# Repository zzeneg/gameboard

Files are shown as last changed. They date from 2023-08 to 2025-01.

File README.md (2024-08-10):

# gameboard

Half-keyboard optimized for gaming.

## Features

- 31 regular MX or KS-33/27 switches
- 5-way switch
- 3 push buttons
- per-key LEDs
- 3D printed case

## Photos

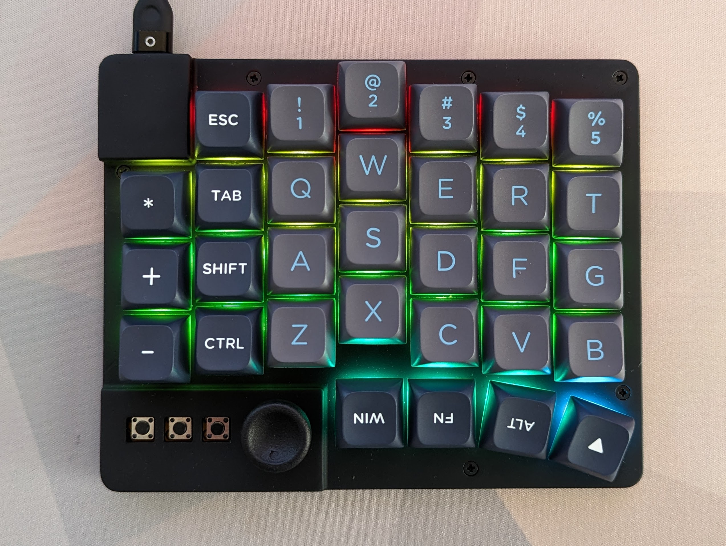
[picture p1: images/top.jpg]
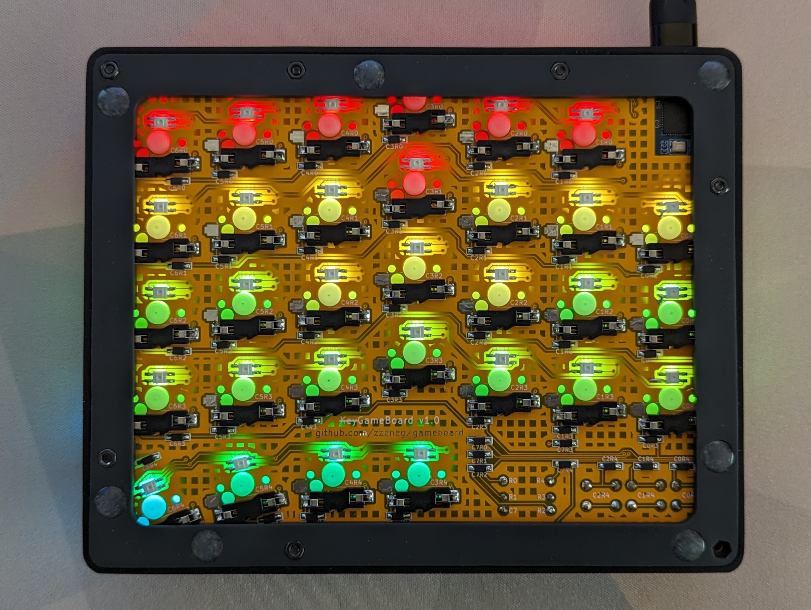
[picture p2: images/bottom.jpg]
 

## Layout

Optimized for regular WASD setup similar to a normal keyboard, to avoid (or at least minimize) remapping keys for games.

No layer-tap and mod-taps to avoid conflicts (many games require mod presses or holding alpha keys).

1 additional layer to access missing half of keyboard.

Anyway it's easy to change keys on the fly with VIAL.
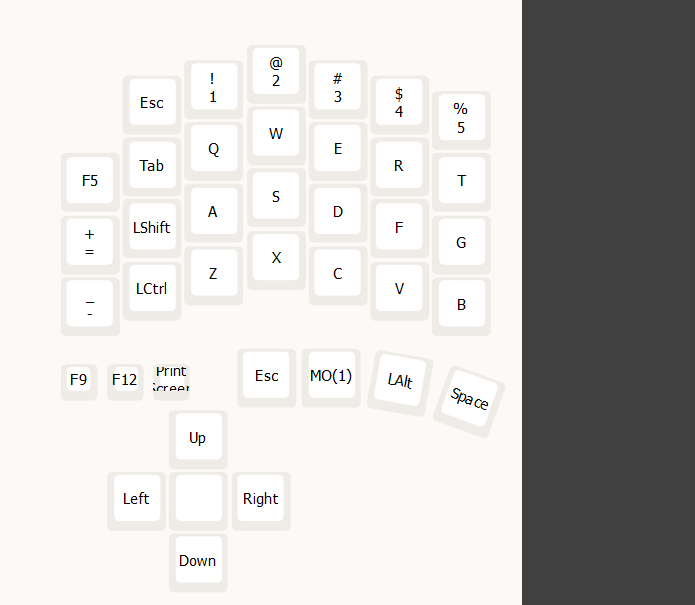
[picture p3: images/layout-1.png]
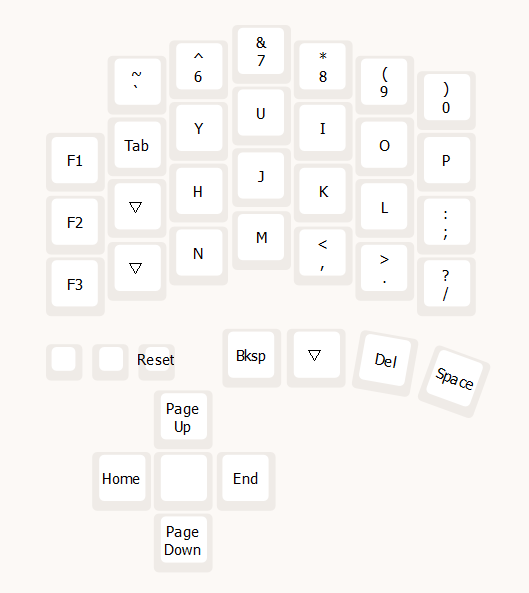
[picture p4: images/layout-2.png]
 

## Case

Tested on JLCPCB resin printing, it may be a bit tight for FDM.

- [KS-33 Top](./case/top.stl)
- [MX Top](./case/top-mx.stl)
- [Bottom](./case/bottom.stl)
- [5-way knob](./case/5way-short.stl) - lower profile knob, if you want higher profile check out ones from [@sadekbaroudi](https://github.com/sadekbaroudi/fingerpunch/tree/master/3d-models/5-way-tactile-switch-knobs)

## Gerber files

- [PCB](./pcb/production/pcb.zip)

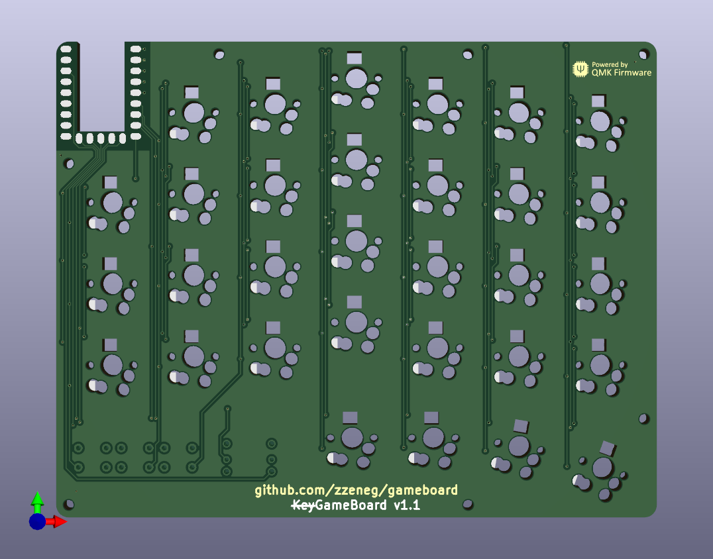
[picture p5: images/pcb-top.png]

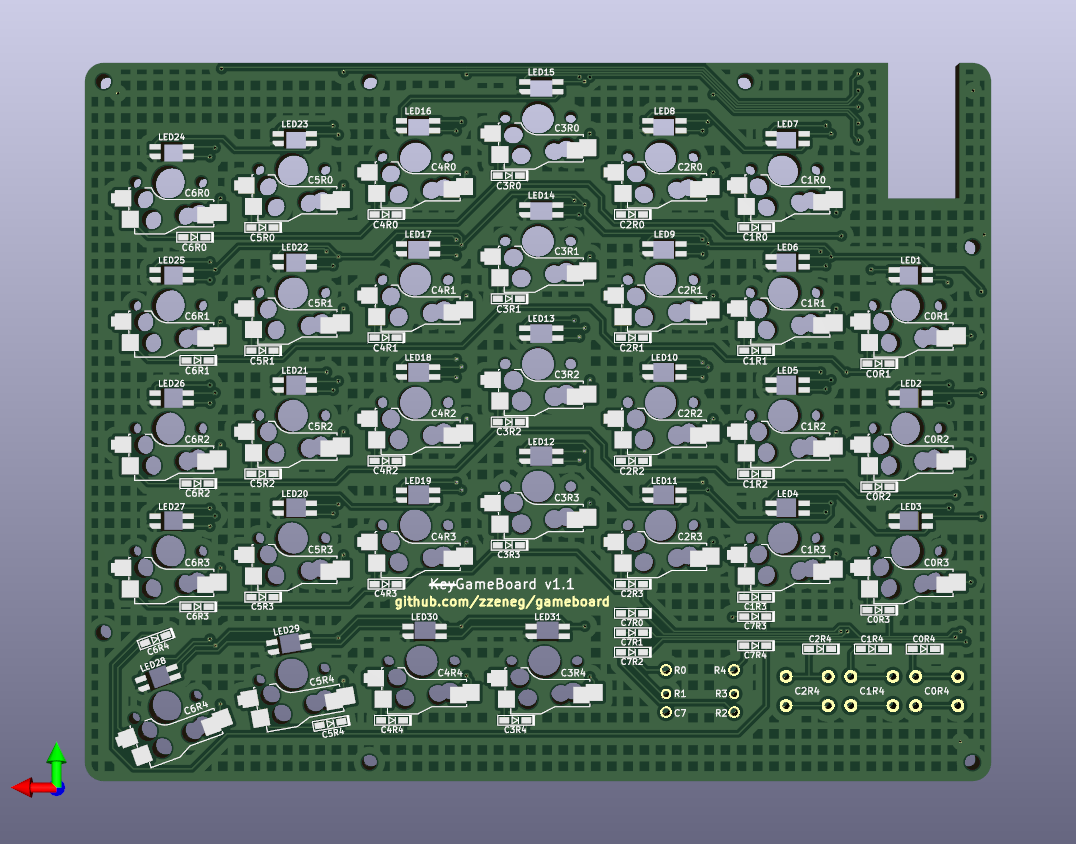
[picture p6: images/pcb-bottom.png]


## VIAL firmware

- [source code](https://github.com/zzeneg/vial-qmk/tree/feature/zzeneg/keyboards/gameboard)
- [pre-compiled V1](https://github.com/zzeneg/vial-qmk/releases/download/zzeneg/gameboard_v1_vial.uf2)
- [pre-compiled V2 (with display)](https://github.com/zzeneg/vial-qmk/releases/download/zzeneg/gameboard_v2_vial.uf2)

## Bill of materials

- [PCB](./pcb/production/pcb.zip)
- 3D printed parts (top, bottom, knob)
- Waveshare [RP2040 Zero](https://www.aliexpress.com/item/3256804090654134.html) MCU
- 39 [SMD SOD-123 1N4148](https://www.aliexpress.com/item/1005002882901030.html) diodes
- 1 [5way switch](https://www.aliexpress.com/item/4000681560472.html)
- 3 [push buttons](https://www.aliexpress.com/item/32912263133.html) - default height is 4.3mm but you can use 6-8mm if you want easier access to them
- 31 [RGB LEDs](https://www.aliexpress.com/item/1005003636607308.html)
- [M2 screws with flat head](https://www.aliexpress.com/item/4001248931159.html) - 8mm for MX or 8mm+6mm for KS
- [M2 nuts](https://www.aliexpress.com/item/1005001412230125.html)
- [7x1.5 legs](https://www.aliexpress.com/item/1005002995402961.html)

## Build guide

Please see my [stront guide](https://github.com/zzeneg/stront/blob/main/build-guide/choc/readme.md) for detailed instructions on soldering diodes/LEDs/sockets/MCU.

## MinY version (V2 - ProMicro-compatible, VIK support)

> [!CAUTION]
> This is special version designed for minimal vertical spacing (19x16mm). Regular keycaps will not fit, you must print your own. I prepared several [keycap sets](./case/minY/keycaps/) to choose.
>
> It uses Pro Micro format MCU so it could be wireless (not tested).
>
> I did not make/test case for MX switches - you can modify it in Fusion.

Updated BOM:

- [MCU](https://www.aliexpress.com/item/1005006130019224.html) - ProMicro pinout, bottom pins are needed for I2C and LED only
- [1.47" bare LCD](https://www.aliexpress.com/item/1005004833011998.html) with [VIK adapter](https://github.com/zzeneg/vik-display-adapter) (**PCB <= 1.2mm is recommended**)
- M2 [heatset inserts](https://www.aliexpress.com/item/1005004624377733.html) - 4mm length, 3.2mm diameter for resin case or 3.5mm for Nylon/PLA
- [push buttons](https://www.aliexpress.com/item/1005006143163980.html) - 10mm height for KS, 15mm for MX
- [push button caps](https://www.aliexpress.com/item/1005001584967258.html) - 3.1 inner diameter

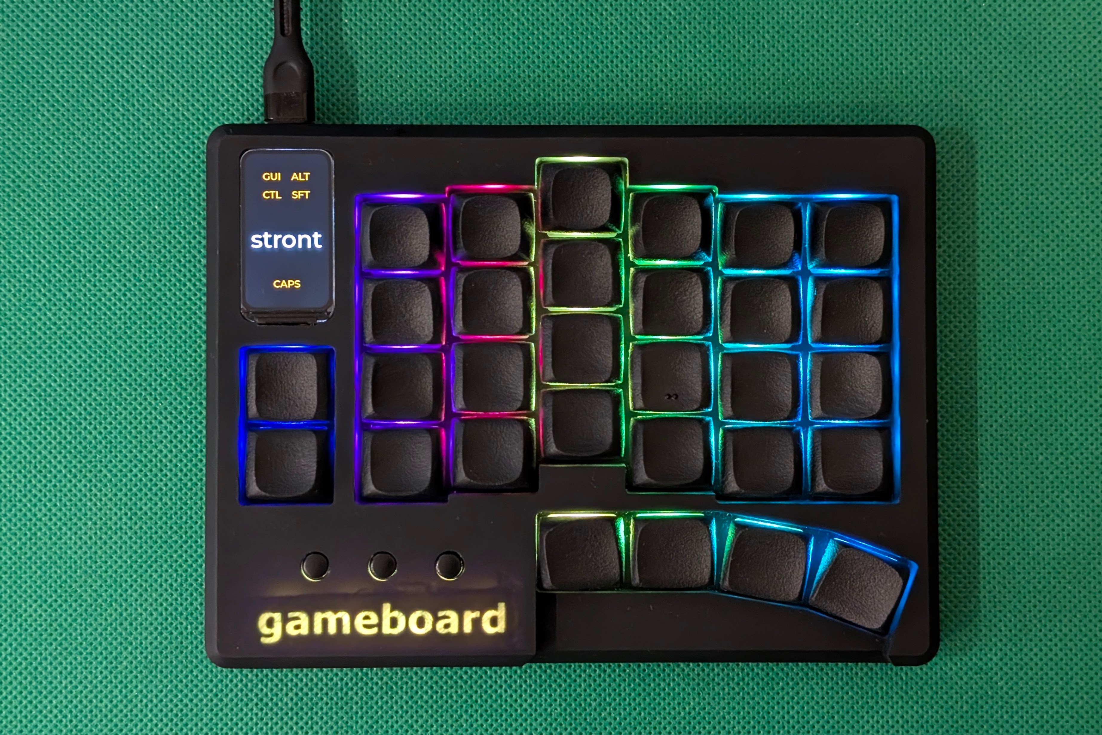
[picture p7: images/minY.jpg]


## Development

For proper KiCad setup install my [zzkeeb](https://github.com/zzeneg/zzkeeb/blob/main/README.md#installation) library

## Support

If you like my work and want to support my future designs, please consider [sponsorship](https://github.com/sponsors/zzeneg).

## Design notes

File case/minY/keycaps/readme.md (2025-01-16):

# Keycap sets for Gameboard MinY

Keycaps with minimal vertical spacing (19x16mm), sprued and adjusted to number of keys on Gameboard.

## DES minY minZ

Generated from [my fork](https://github.com/zzeneg/PseudoMakeMeKeyCapProfiles?tab=readme-ov-file#update-from-zzeneg).

Tested in MJF Nylon with KS-33, ChocV2, Tecsee Medium and regular MX switches.

## CMY

Alternative profile, see [CMY](https://github.com/sadekbaroudi/fingerpunch/tree/master/keycaps/CMY) from Sadek Baroudi.

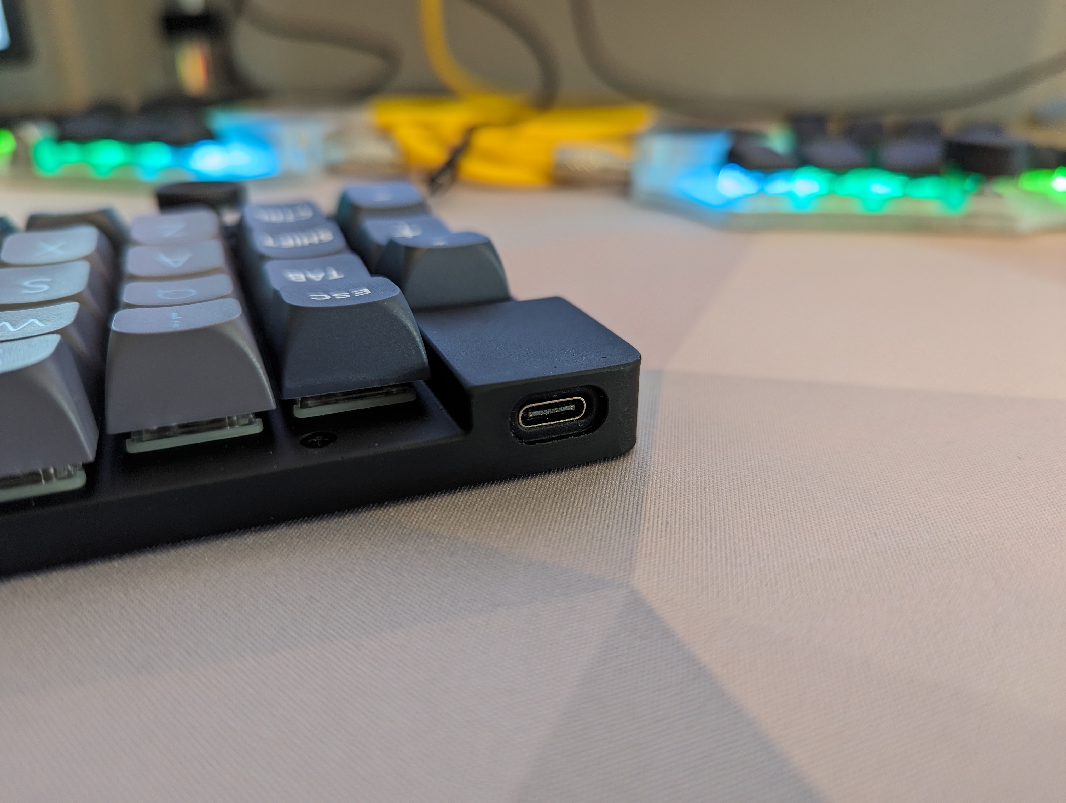
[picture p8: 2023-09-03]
images/usb.jpg

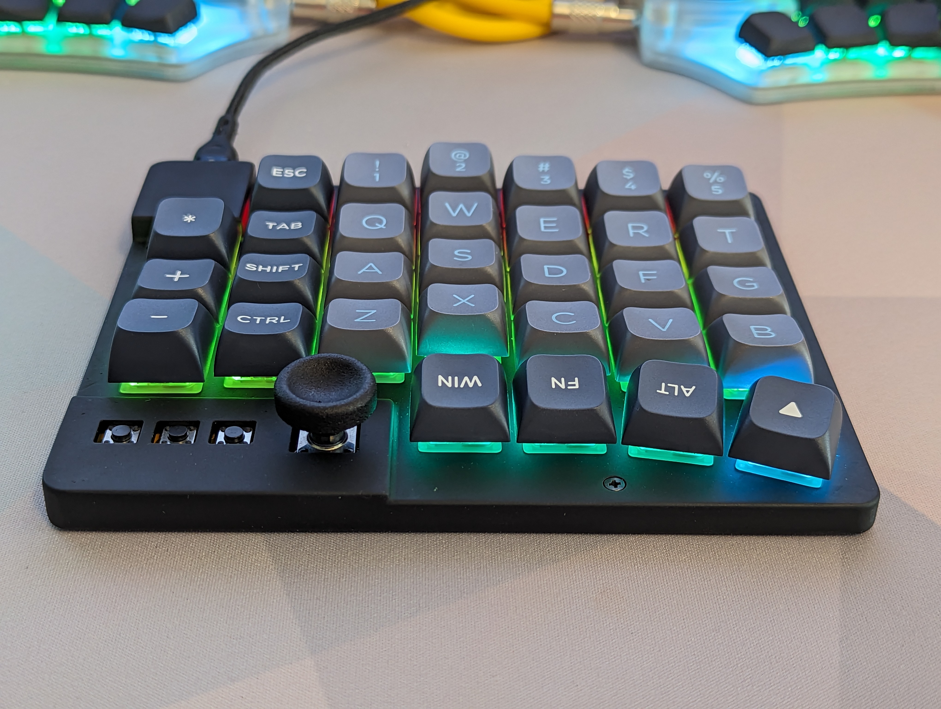
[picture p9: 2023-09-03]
images/side.jpg

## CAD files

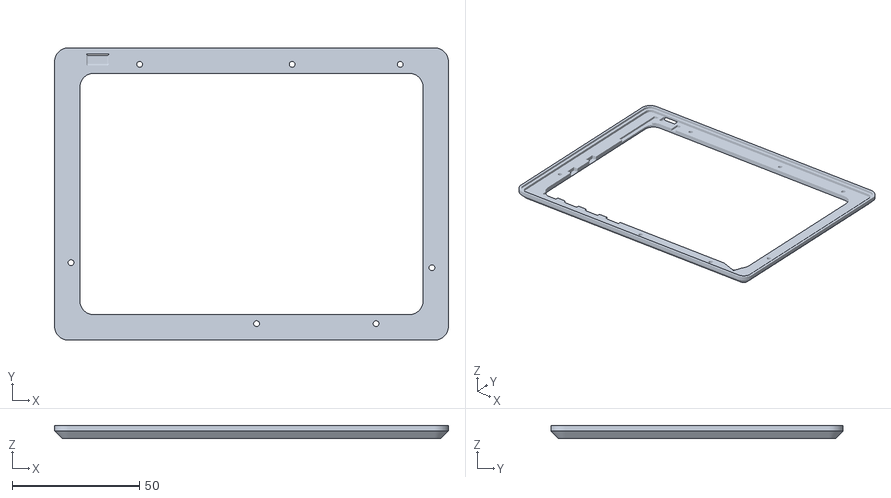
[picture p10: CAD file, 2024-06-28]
case/minY/miny-v2-ks-bottom-wireless.stl
155.0 x 115.0 x 5.10

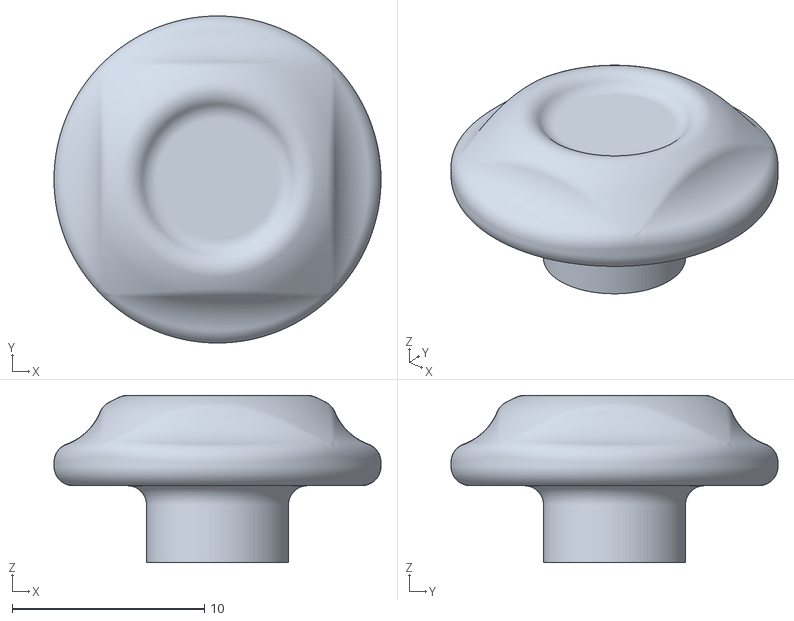
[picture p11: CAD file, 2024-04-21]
case/mushroom-directional-ks.stl
17.0 x 17.0 x 8.70

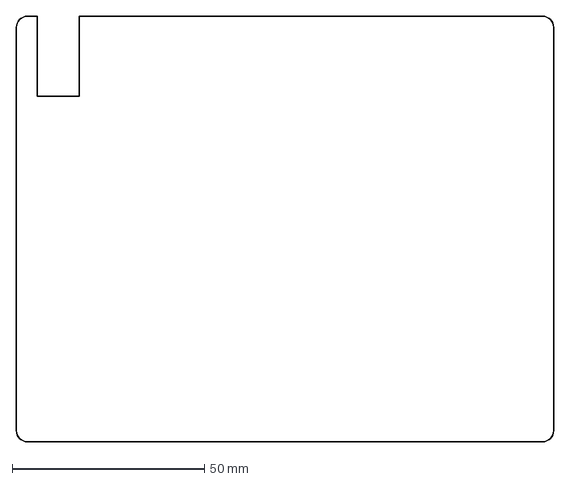
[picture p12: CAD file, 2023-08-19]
pcb/pcb.dxf
139.8 x 110.8 mm

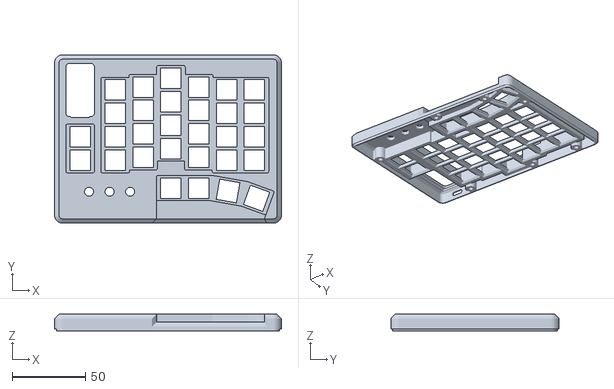
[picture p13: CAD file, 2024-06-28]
case/minY/miny-v2-ks-top.stl
155.0 x 115.0 x 11.4

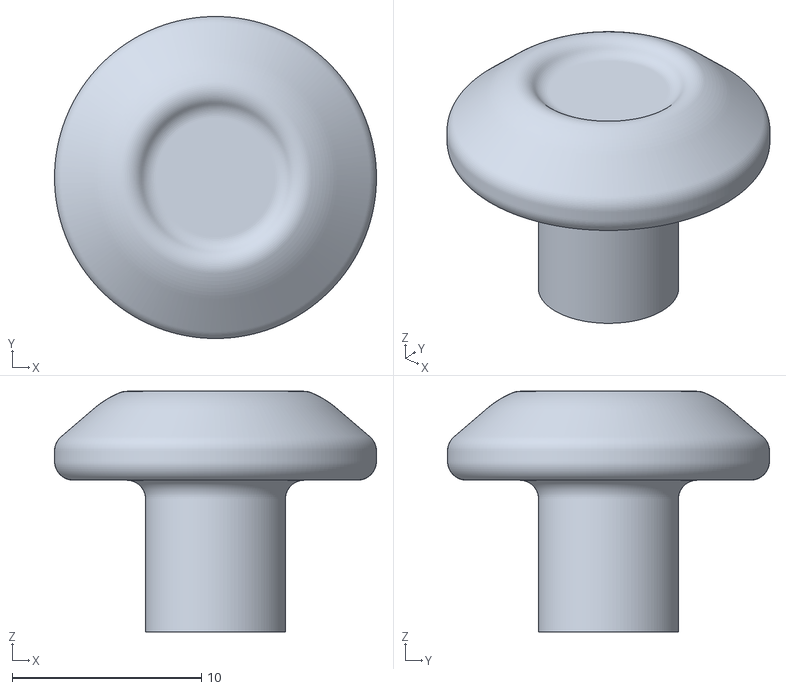
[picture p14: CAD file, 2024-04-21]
case/mushroom-mx.stl
17.0 x 17.0 x 12.7

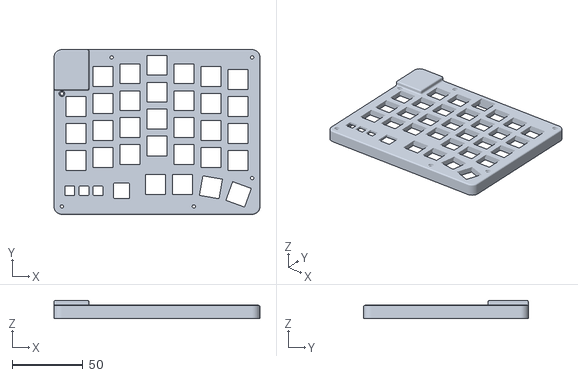
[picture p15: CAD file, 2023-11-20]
case/top-mx.stl
145.2 x 116.1 x 12.8

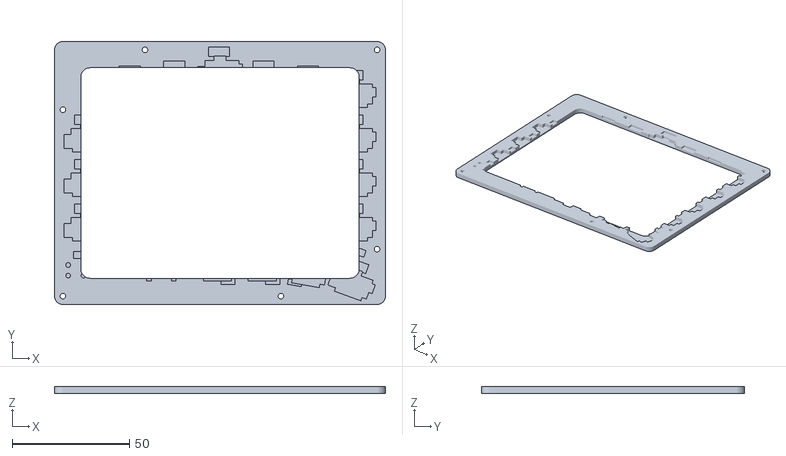
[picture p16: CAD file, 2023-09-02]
case/bottom.stl
141.2 x 112.2 x 2.80

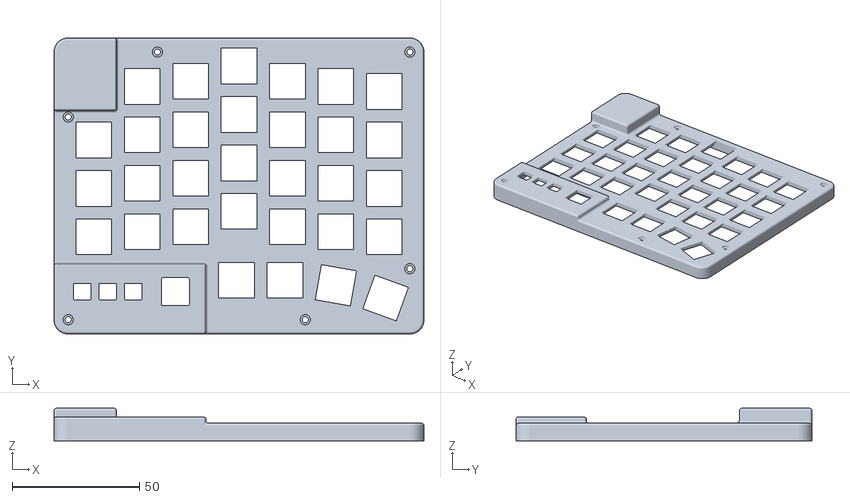
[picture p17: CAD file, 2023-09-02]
case/top.stl
145.2 x 116.1 x 12.8

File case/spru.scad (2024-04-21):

spacing = 18;
r = 0.8;

// add all STLs
stls = [ "/mushroom-directional-mx.stl", "./mushroom-directional-ks.stl" ];

union() {
  count = len(stls);

  for (i = [0:count - 1]) {
    translate([ 0, i * spacing, 0 ]) import(stls[i]);
  }

  translate([ 4.4, -spacing / 2 * 0.9, 0.9 * r ]) rotate([ 270, 0, 0 ])
      cylinder(h = (count)*spacing - spacing * 0.1, r = r, $fn = 15);
};

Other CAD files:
case/minY/miny-v2-ks-bottom.stl
case/mushroom-ks.stl
case/mushroom-directional-mx.stl

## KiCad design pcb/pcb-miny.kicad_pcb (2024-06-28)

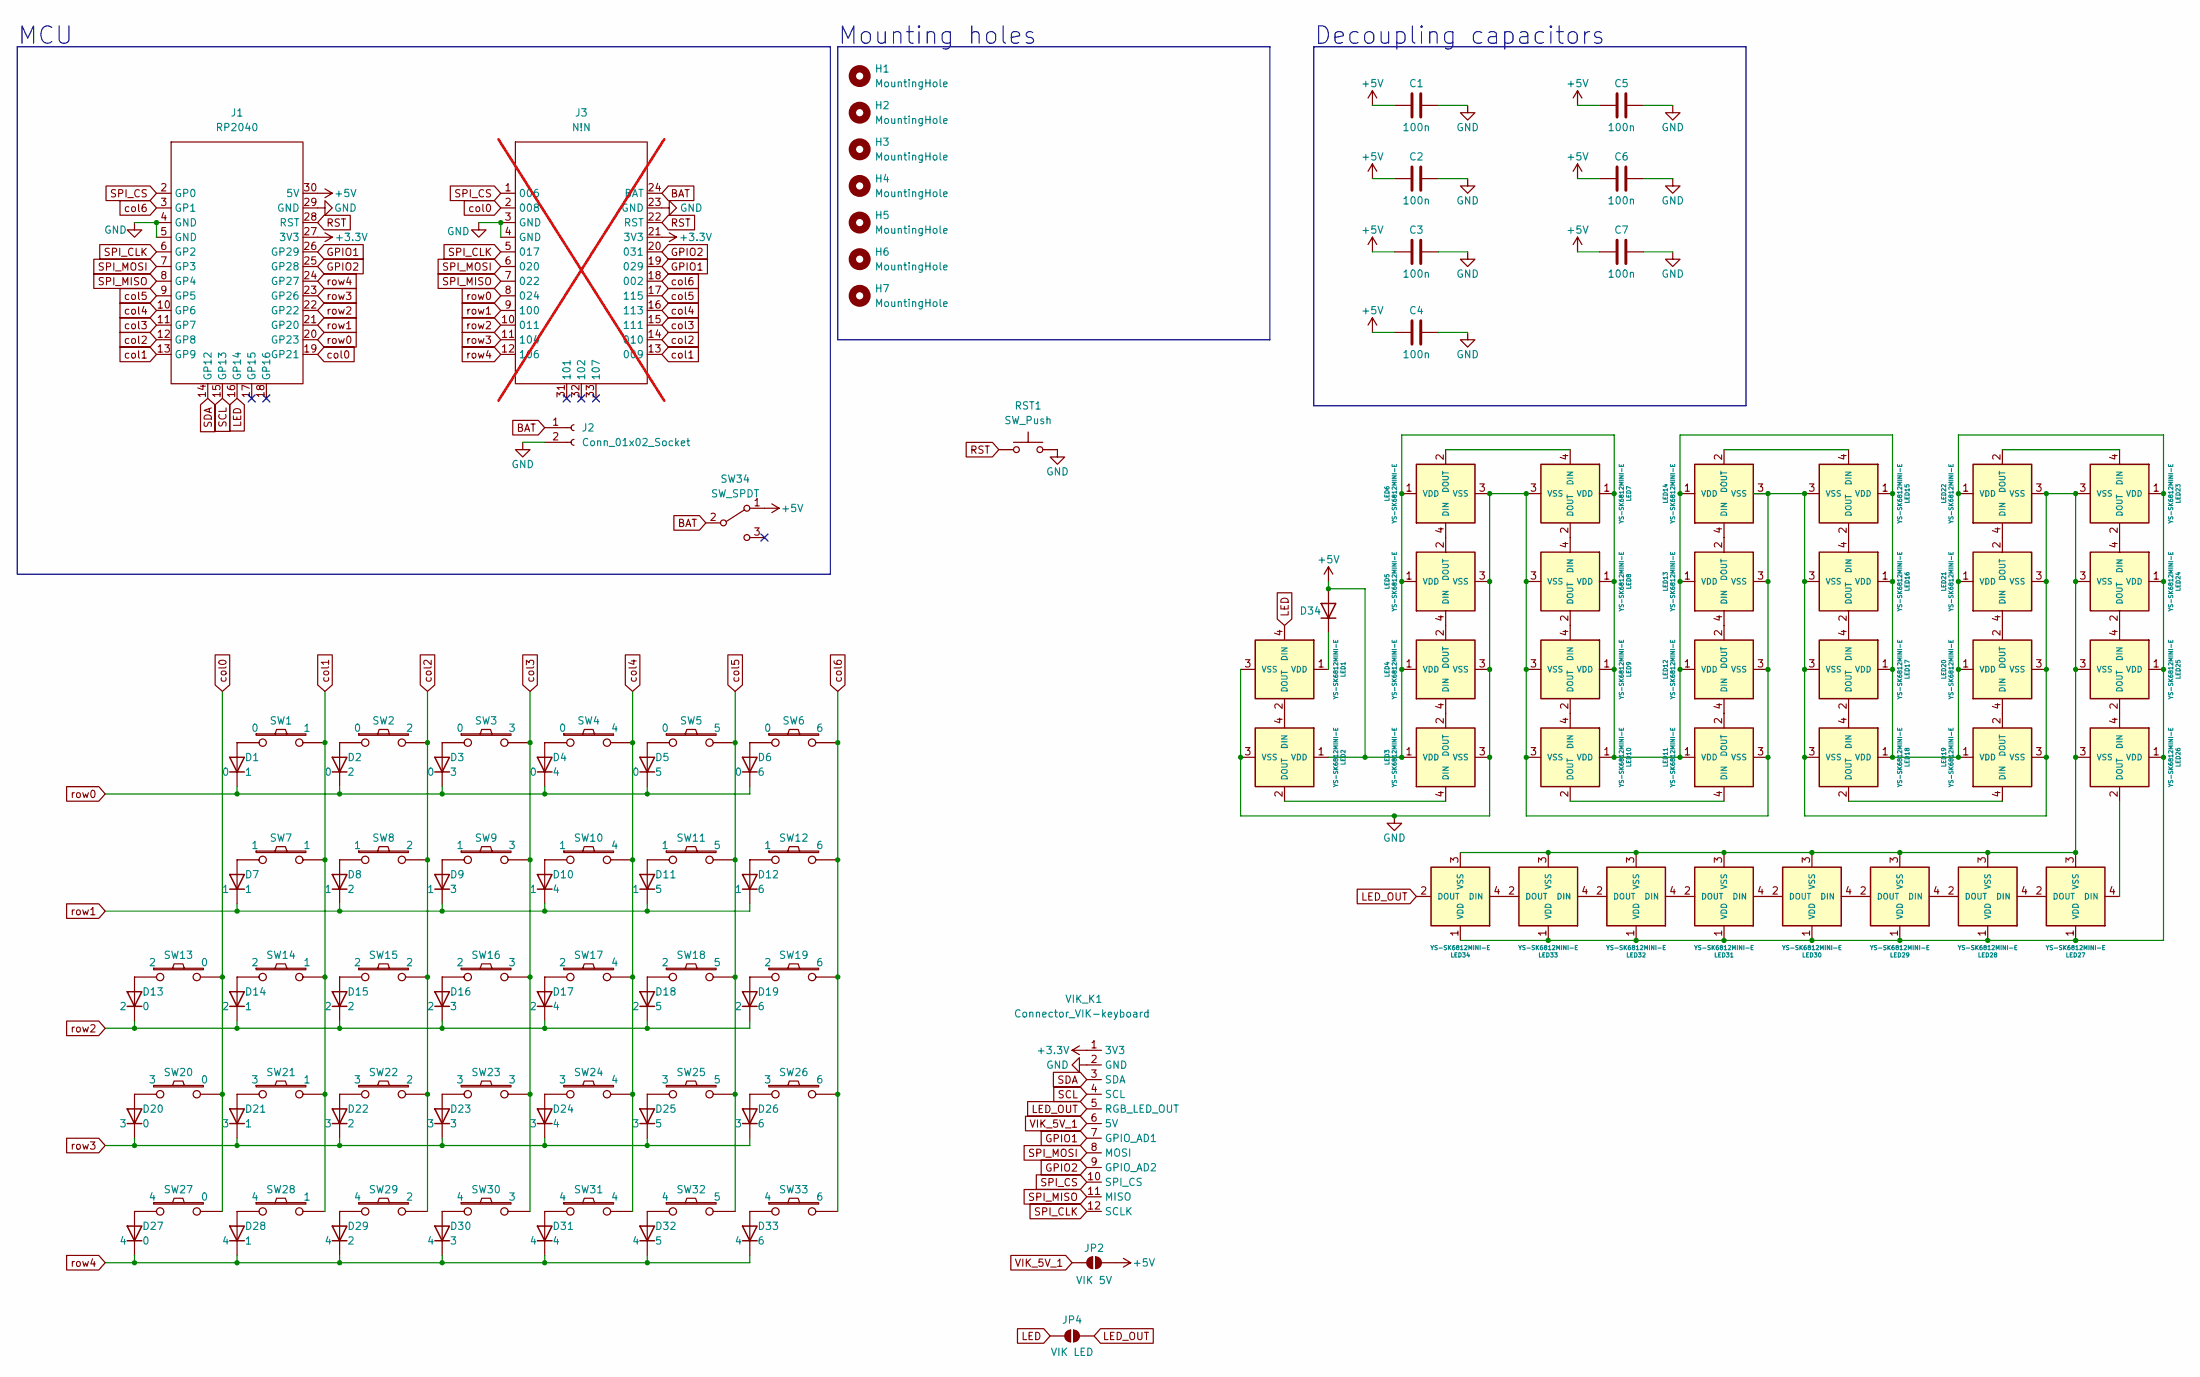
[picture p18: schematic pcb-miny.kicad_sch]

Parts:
C1, C2, C3, C4, C5, C6, C7: 100n; C_1206_3216Metric_Pad1.33x1.80mm_HandSolder
D1, D2, D3, D4, D5, D6, D7, D8, D9, D10, D11, D12, D13, D14, D15, D16, D17, D18, D19, D20, D21, D22, D23, D24, D25, D26, D27, D28, D29, D30, D31, D32, D33, D34: D; Diode_1N4148-SOD123
H1, H2, H3, H4, H5, H6, H7: MountingHole; Hole_M2
J1: RP2040; MCU_rp2040-helios
J2: Conn_01x02_Socket; Connector_JST-1x02-2.00mm
J3: N!N; MCU_nice-nano; not fitted
JP2: VIK 5V; SolderJumper-2_P1.3mm_Open_RoundedPad1.0x1.5mm
JP4: VIK LED; SolderJumper-2_P1.3mm_Open_RoundedPad1.0x1.5mm
LED1, LED2, LED3, LED4, LED5, LED6, LED7, LED8, LED9, LED10, LED11, LED12, LED13, LED14, LED15, LED16, LED17, LED18, LED19, LED20, LED21, LED22, LED23, LED24, LED25, LED26, LED27, LED28, LED29, LED30, LED31, LED32, LED33, LED34: YS-SK6812MINI-E; LED_SK6812-MINI-E
RST1: SW_Push; Button_SW_SPST_SKQG_WithoutStem
SW1, SW2, SW3, SW4, SW5, SW6, SW7, SW8, SW9, SW10, SW11, SW12, SW13, SW14, SW15, SW16, SW17, SW18, SW19, SW20, SW21, SW22, SW23, SW24, SW25, SW26, SW30, SW31, SW32, SW33: Switch; Switch_MXKS-miny-hotswap-south-ks3d
SW27, SW28, SW29: Switch; Button_Push-6mm
SW34: SW_SPDT; Switch_SPDT-PCM12
VIK_K1: Connector_VIK-keyboard; Connector_VIK-horizontal-keyboard

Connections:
+3.3V: J1.27 (3V3), J3.21 (3V3), VIK_K1.1 (3V3)
+5V: C1.1, C2.1, C3.1, C4.1, C5.1, C6.1, C7.1, D34.2 (A), J1.30 (5V), JP2.1 (A), LED2.1 (VDD), LED3.1 (VDD), LED4.1 (VDD), LED5.1 (VDD), LED6.1 (VDD), LED7.1 (VDD), LED8.1 (VDD), LED9.1 (VDD), LED10.1 (VDD), LED11.1 (VDD), LED12.1 (VDD), LED13.1 (VDD), LED14.1 (VDD), LED15.1 (VDD), LED16.1 (VDD), LED17.1 (VDD), LED18.1 (VDD), LED19.1 (VDD), LED20.1 (VDD), LED21.1 (VDD), LED22.1 (VDD), LED23.1 (VDD), LED24.1 (VDD), LED25.1 (VDD), LED26.1 (VDD), LED27.1 (VDD), LED28.1 (VDD), LED29.1 (VDD), LED30.1 (VDD), LED31.1 (VDD), LED32.1 (VDD), LED33.1 (VDD), LED34.1 (VDD), SW34.1 (A)
BAT: J2.1, J3.24 (BAT), SW34.2 (B)
GND: C1.2, C2.2, C3.2, C4.2, C5.2, C6.2, C7.2, J1.4 (GND), J1.5 (GND), J1.29 (GND), J2.2, J3.3 (GND), J3.4 (GND), J3.23 (GND), LED1.3 (VSS), LED2.3 (VSS), LED3.3 (VSS), LED4.3 (VSS), LED5.3 (VSS), LED6.3 (VSS), LED7.3 (VSS), LED8.3 (VSS), LED9.3 (VSS), LED10.3 (VSS), LED11.3 (VSS), LED12.3 (VSS), LED13.3 (VSS), LED14.3 (VSS), LED15.3 (VSS), LED16.3 (VSS), LED17.3 (VSS), LED18.3 (VSS), LED19.3 (VSS), LED20.3 (VSS), LED21.3 (VSS), LED22.3 (VSS), LED23.3 (VSS), LED24.3 (VSS), LED25.3 (VSS), LED26.3 (VSS), LED27.3 (VSS), LED28.3 (VSS), LED29.3 (VSS), LED30.3 (VSS), LED31.3 (VSS), LED32.3 (VSS), LED33.3 (VSS), LED34.3 (VSS), RST1.2, VIK_K1.2 (GND)
GPIO1: J1.26 (GP29), J3.19 (029), VIK_K1.7 (GPIO_AD1)
GPIO2: J1.25 (GP28), J3.20 (031), VIK_K1.9 (GPIO_AD2)
LED: J1.16 (GP14), JP4.1 (A), LED1.4 (DIN)
LED_OUT: JP4.2 (B), LED34.2 (DOUT), VIK_K1.5 (RGB_LED_OUT)
unnamed: D1.2 (A), SW1.1
unnamed: D2.2 (A), SW2.1
unnamed: D3.2 (A), SW3.1
unnamed: D4.2 (A), SW4.1
unnamed: D5.2 (A), SW5.1
unnamed: D6.2 (A), SW6.1
unnamed: D7.2 (A), SW7.1
unnamed: D8.2 (A), SW8.1
unnamed: D9.2 (A), SW9.1
unnamed: D10.2 (A), SW10.1
unnamed: D11.2 (A), SW11.1
unnamed: D12.2 (A), SW12.1
unnamed: D13.2 (A), SW13.1
unnamed: D14.2 (A), SW14.1
unnamed: D15.2 (A), SW15.1
unnamed: D16.2 (A), SW16.1
unnamed: D17.2 (A), SW17.1
unnamed: D18.2 (A), SW18.1
unnamed: D19.2 (A), SW19.1
unnamed: D20.2 (A), SW20.1
unnamed: D21.2 (A), SW21.1
unnamed: D22.2 (A), SW22.1
unnamed: D23.2 (A), SW23.1
unnamed: D24.2 (A), SW24.1
unnamed: D25.2 (A), SW25.1
unnamed: D26.2 (A), SW26.1
unnamed: D27.2 (A), SW27.1
unnamed: D28.2 (A), SW28.1
unnamed: D29.2 (A), SW29.1
unnamed: D30.2 (A), SW30.1
unnamed: D31.2 (A), SW31.1
unnamed: D32.2 (A), SW32.1
unnamed: D33.2 (A), SW33.1
unnamed: D34.1 (K), LED1.1 (VDD)
unnamed: LED1.2 (DOUT), LED2.4 (DIN)
unnamed: LED2.2 (DOUT), LED3.4 (DIN)
unnamed: LED3.2 (DOUT), LED4.4 (DIN)
unnamed: LED4.2 (DOUT), LED5.4 (DIN)
unnamed: LED5.2 (DOUT), LED6.4 (DIN)
unnamed: LED6.2 (DOUT), LED7.4 (DIN)
unnamed: LED7.2 (DOUT), LED8.4 (DIN)
unnamed: LED8.2 (DOUT), LED9.4 (DIN)
unnamed: LED9.2 (DOUT), LED10.4 (DIN)
unnamed: LED10.2 (DOUT), LED11.4 (DIN)
unnamed: LED11.2 (DOUT), LED12.4 (DIN)
unnamed: LED12.2 (DOUT), LED13.4 (DIN)
unnamed: LED13.2 (DOUT), LED14.4 (DIN)
unnamed: LED14.2 (DOUT), LED15.4 (DIN)
unnamed: LED15.2 (DOUT), LED16.4 (DIN)
unnamed: LED16.2 (DOUT), LED17.4 (DIN)
unnamed: LED17.2 (DOUT), LED18.4 (DIN)
unnamed: LED18.2 (DOUT), LED19.4 (DIN)
unnamed: LED19.2 (DOUT), LED20.4 (DIN)
unnamed: LED20.2 (DOUT), LED21.4 (DIN)
unnamed: LED21.2 (DOUT), LED22.4 (DIN)
unnamed: LED22.2 (DOUT), LED23.4 (DIN)
unnamed: LED23.2 (DOUT), LED24.4 (DIN)
unnamed: LED24.2 (DOUT), LED25.4 (DIN)
unnamed: LED25.2 (DOUT), LED26.4 (DIN)
unnamed: LED26.2 (DOUT), LED27.4 (DIN)
unnamed: LED27.2 (DOUT), LED28.4 (DIN)
unnamed: LED28.2 (DOUT), LED29.4 (DIN)
unnamed: LED29.2 (DOUT), LED30.4 (DIN)
unnamed: LED30.2 (DOUT), LED31.4 (DIN)
unnamed: LED31.2 (DOUT), LED32.4 (DIN)
unnamed: LED32.2 (DOUT), LED33.4 (DIN)
unnamed: LED33.2 (DOUT), LED34.4 (DIN)
RST: J1.28 (RST), J3.22 (RST), RST1.1
SCL: J1.15 (GP13), VIK_K1.4 (SCL)
SDA: J1.14 (GP12), VIK_K1.3 (SDA)
SPI_CLK: J1.6 (GP2), J3.5 (017), VIK_K1.12 (SCLK)
SPI_CS: J1.2 (GP0), J3.1 (006), VIK_K1.10 (SPI_CS)
SPI_MISO: J1.8 (GP4), J3.7 (022), VIK_K1.11 (MISO)
SPI_MOSI: J1.7 (GP3), J3.6 (020), VIK_K1.8 (MOSI)
VIK_5V_1: JP2.2 (B), VIK_K1.6 (5V)
col0: J1.19 (GP21), J3.2 (008), SW13.2, SW20.2, SW27.2
col1: J1.13 (GP9), J3.13 (009), SW1.2, SW7.2, SW14.2, SW21.2, SW28.2
col2: J1.12 (GP8), J3.14 (010), SW2.2, SW8.2, SW15.2, SW22.2, SW29.2
col3: J1.11 (GP7), J3.15 (111), SW3.2, SW9.2, SW16.2, SW23.2, SW30.2
col4: J1.10 (GP6), J3.16 (113), SW4.2, SW10.2, SW17.2, SW24.2, SW31.2
col5: J1.9 (GP5), J3.17 (115), SW5.2, SW11.2, SW18.2, SW25.2, SW32.2
col6: J1.3 (GP1), J3.18 (002), SW6.2, SW12.2, SW19.2, SW26.2, SW33.2
row0: D1.1 (K), D2.1 (K), D3.1 (K), D4.1 (K), D5.1 (K), D6.1 (K), J1.20 (GP23), J3.8 (024)
row1: D7.1 (K), D8.1 (K), D9.1 (K), D10.1 (K), D11.1 (K), D12.1 (K), J1.21 (GP20), J3.9 (100)
row2: D13.1 (K), D14.1 (K), D15.1 (K), D16.1 (K), D17.1 (K), D18.1 (K), D19.1 (K), J1.22 (GP22), J3.10 (011)
row3: D20.1 (K), D21.1 (K), D22.1 (K), D23.1 (K), D24.1 (K), D25.1 (K), D26.1 (K), J1.23 (GP26), J3.11 (104)
row4: D27.1 (K), D28.1 (K), D29.1 (K), D30.1 (K), D31.1 (K), D32.1 (K), D33.1 (K), J1.24 (GP27), J3.12 (106)

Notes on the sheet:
Decoupling capacitors
Mounting holes
MCU

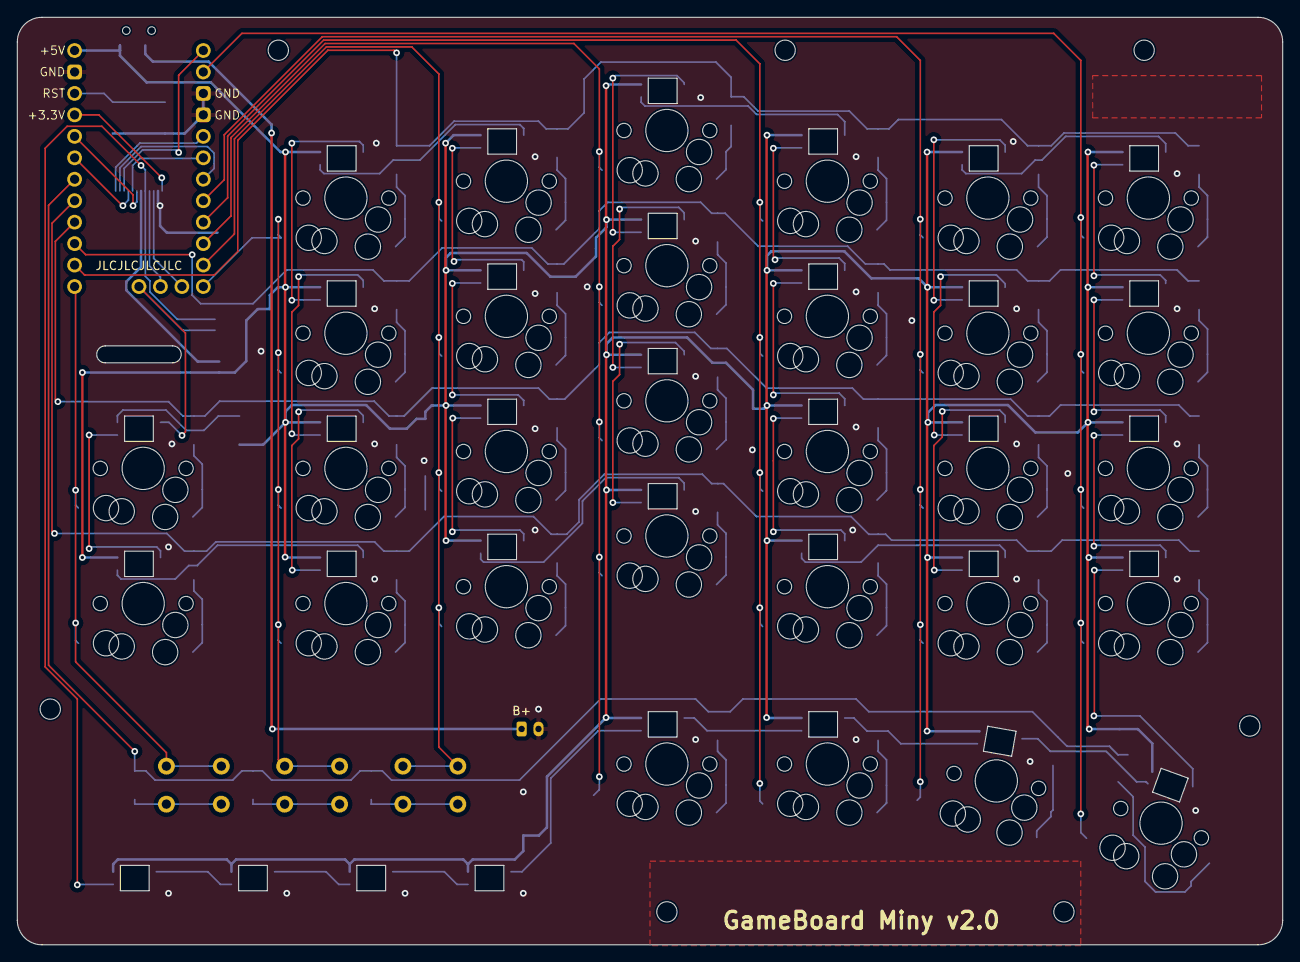
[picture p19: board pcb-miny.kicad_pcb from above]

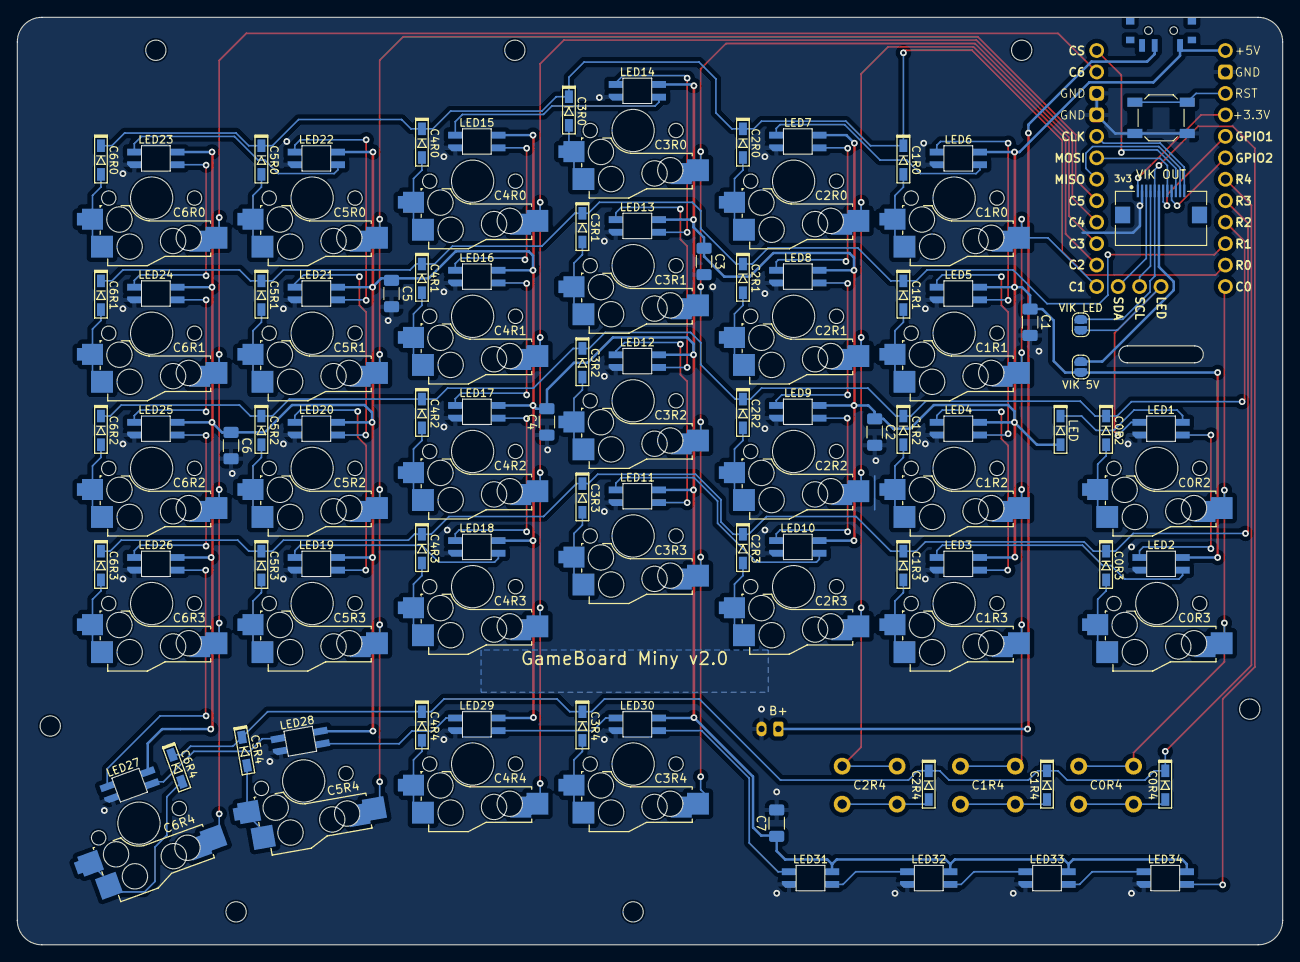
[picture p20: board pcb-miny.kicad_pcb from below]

Board: 2 copper layers, 149.8 x 109.8 mm, 122 parts (81 on the bottom side), 95 nets.

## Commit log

2023-08-19 add pcb
    [pcb.kicad_pcb, pcb.kicad_sch]
2023-08-19 pcb updates
    [pcb.dxf, pcb.kicad_pcb]
2023-08-19 add case
    [Gameboard v13.f3z, bottom.stl, top.stl]
2023-09-01 PCB 1.1
    [pcb.kicad_pcb, pcb.kicad_sch]
2023-09-02 update case
    [Gameboard v13.f3z, bottom.stl, top.stl]
2023-11-20 add MX case
    [top-mx.stl]
2024-01-10 add miny
    [miny-bottom.stl, miny-top.stl, musroom-directional.stl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]
2024-01-13 add TPU case
    [miny-bottom.stl, miny-ks-top.stl, miny-top.stl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]
2024-01-13 add CMY keycaps
    [CMY-MX-R2-R4-12deg-x4.stl, CMY-MX-R2-R4-5deg-x5.stl, CMY-MX-R3-12deg-x4.stl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]
2024-01-13 add decoupling capacitors
    [pcb-miny.kicad_pcb, pcb-miny.kicad_sch]
2024-02-04 update tpu case, add mx
    [miny-tpu-mx-plate.stl, miny-tpu-mx-top.stl, mushroom-directional-mx.stl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]
2024-02-04 remove miny case (not tested)
    [miny-bottom.stl, miny-ks-top.stl, mushroom-directional-ks.stl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]
2024-02-04 fix KS case after updates
    [miny-tpu-ks-plate.stl, miny-tpu-ks-top.stl, mushroom-ks-x2.stl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]
2024-02-16 add DES keycaps
    [CMY-MX-R2-R4-12deg-x4.stl, CMY-MX-R2-R4-5deg-x5.stl, CMY-MX-R3-12deg-x4.stl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]
2024-04-15 restructure project
    [pcb.kicad_pcb, pcb.kicad_sch]
2024-04-21 small minY case updates
    [miny-tpu-ks-plate.stl, miny-tpu-ks-top.stl, miny-tpu-mx-plate.stl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]
2024-05-02 miny-v2 draft
    [miny-v2-ks-bottom-wireless.stl, miny-v2-ks-bottom.stl, miny-v2-ks-top.stl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]
2024-05-03 fix chamfer
    [miny-v2-ks-bottom-wireless.stl, miny-v2-ks-bottom.stl, miny-v2-ks-top.stl]
2024-05-03 small pcb updates, rounded
    [pcb-miny-rounded.kicad_pcb, pcb-miny.kicad_pcb]
2024-05-26 fix rounded pcb
    [pcb-miny-rounded.kicad_pcb]
2024-05-30 add more screw holes, remove rounded pcb
    [pcb-miny-rounded.kicad_pcb, pcb-miny.kicad_pcb, pcb-miny.kicad_sch]
2024-05-30 update minY case
    [miny-v2-ks-bottom-wireless.stl, miny-v2-ks-bottom.stl, miny-v2-ks-top.stl]
2024-06-26 final case and pcb
    [miny-v2-ks-bottom-wireless.stl, miny-v2-ks-bottom.stl, miny-v2-ks-top.stl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]
2024-06-28 remove minY v1
    [miny-tpu-ks-plate.stl, miny-tpu-ks-top.stl, miny-tpu-mx-plate.stl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]
2025-01-16 update des keycaps
